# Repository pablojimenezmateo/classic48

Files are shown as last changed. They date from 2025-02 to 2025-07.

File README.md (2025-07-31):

# Classic 48
A custom 48 key split keyboard

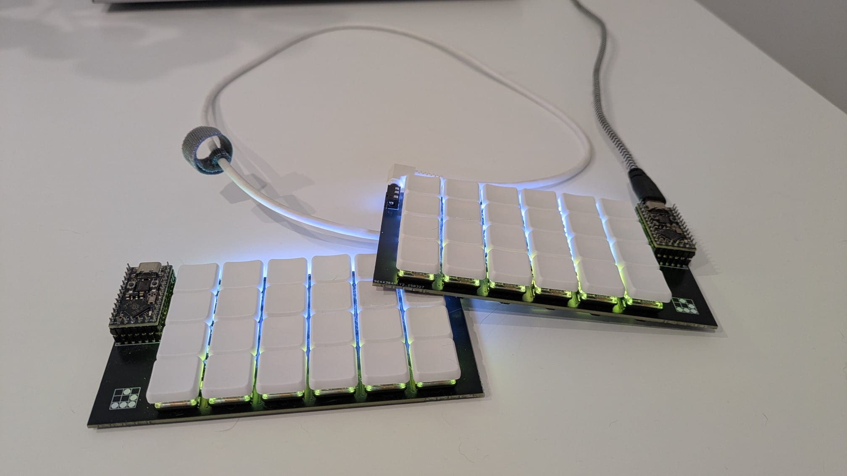
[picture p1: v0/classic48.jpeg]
classic48


# Bill Of Materials
| Name | Quantity/Variety | Item Price (€) | Shipping (€) | Link |
|--|--|--|--|--|
|Brown Choc Switches|70 pcs|47.59|0|[AliExpress](https://www.aliexpress.com/item/1005005883472162.html?spm=a2g0o.order_list.order_list_main.199.2613194dDxt0T9)|
|Choc Keycaps|10 x B type (5 pcs each)|20|4.86|[AliExpress](https://www.aliexpress.com/item/1005007966026757.html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)|
|Choc Blind Keycaps|1 x E type (5 pcs each)|2.99|4.86|[AliExpress](https://www.aliexpress.com/item/1005007966026757.html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)|
|Soldering iron|1|19.69|0|[AliExpress](https://www.aliexpress.com/item/4000019437594.html?spm=a2g0o.order_detail.order_detail_item.3.5b734d1aqwuhYo)|
|SK6812 Mini-E LEDs|1 (100 pcs)|3.49|0.09|[AliExpress](https://www.aliexpress.com/item/1005002865070175.html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)|
|RP2040 Pro Micro|2|6.38|0|[AliExpress](https://www.aliexpress.com/item/1005006787060405.html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)|
|TRRS|1 (10 pcs)|2.11|0|[AliExpress](https://www.aliexpress.com/item/33029465106.html?spm=a2g0o.order_detail.order_detail_item.3.4e99f19crF5m72)|
|Soldering mount|1|8.09|0|[AliExpress](https://www.aliexpress.com/item/1005007045716674.html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)|
|Flux pen|1|1.01|0|[AliExpress](https://www.aliexpress.com/item/1005007346959832.html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)|
|Choc Hot Swap Sockets|1 x Type B (70 pcs)|5.89|0|[AliExpress](https://www.aliexpress.com/item/1005007232040760.html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)|
|SMD diode|1 1N4148W SOD123 (100 pcs)|1.08|0|[AliExpress](https://www.aliexpress.com/item/1005005707644429.html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)|
|Multimeter|1|3.65|0|[AliExpress](https://www.aliexpress.com/item/1005007059884308.html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)|
|Desoldering braid|1 x 1.5mm 1.5m|1.59|0|[AliExpress](https://www.aliexpress.com/item/1005005398523384.html?spm=a2g0o.order_list.order_list_main.138.26131802A570A7)|
|Round female pin header|1 (10 pcs)|3.59|0.81|[AliExpress](https://www.aliexpress.com/item/33036413973.html?spm=a2g0o.order_detail.order_detail_item.3.7ef1f19cFHvYfp)|
|Round male pin header|1 (5 pcs)|2.00|1.31|[AliExpress](https://www.aliexpress.com/item/1005008053808682.html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)|
|PCB|1 (5 pcs)|10.26| 15.87 (shipping) + 29.14 (customs + handling fees DHL)|[JLCPCB](https://jlcpcb.com/)|

Grand total: **196.35 €**

# Installing the kicad libaries
1. Go to KiCad, `Preferences` -> `Configure Paths`, add new row with name `PJIMENEZ` and path to `pjimenez.kicad`
2. Go to KiCad, `Preferences` -> `Manage Footprint Libraries`, add new row with name `pjimenez` and path to `pjimenez.kicad/pjimenez.pretty`
3. Go to KiCad, `Preferences` -> `Manage Symbol Libraries`, add new row with name `pjimenez` and path to `pjimenez.kicad/pjimenez.kicad_sym`

# Firmware
Checkout the [classic48-keymap repository](https://github.com/pablojimenezmateo/classic48-keymap)

# License
This project is licensed under Creative commons Attribution 3.0 Unported, more info : http://creativecommons.org/licenses/by/3.0/deed.en_US

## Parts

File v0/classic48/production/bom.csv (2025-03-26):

Designator | Footprint | Quantity | Value | LCSC Part #
D1, D10, D11, D12, D13, D14, D15, D16, D17, D18, D19, D2, D20, D21, D22, D23, D24, D25, D26, D27, D28, D29, D3, D30, D31, D32, D33, D34, D35, D36, D37, D38, D39, D4, D40, D41, D42, D43, D44, D45, D46, D47, D48, D49, D5, D50, D6, D7, D8, D9 | Diode_1N4148-SOD123 | 50 | Diode_1N4148-SOD123
LED1, LED10, LED11, LED12, LED13, LED14, LED15, LED16, LED17, LED18, LED19, LED2, LED20, LED21, LED22, LED23, LED24, LED25, LED26, LED27, LED28, LED29, LED3, LED30, LED31, LED32, LED33, LED34, LED35, LED36, LED37, LED38, LED39, LED4, LED40, LED41, LED42, LED43, LED44, LED45, LED46, LED47, LED48, LED5, LED6, LED7, LED8, LED9 | LED_SK6812-MINI-E | 48 | LED_SK6812MINI-E
SW1, SW10, SW11, SW12, SW13, SW14, SW15, SW16, SW17, SW18, SW19, SW2, SW20, SW21, SW22, SW23, SW24, SW25, SW26, SW27, SW28, SW29, SW3, SW30, SW31, SW32, SW33, SW34, SW35, SW36, SW37, SW38, SW39, SW4, SW40, SW41, SW42, SW43, SW44, SW45, SW46, SW47, SW48, SW5, SW6, SW7, SW8, SW9 | Switch_ChocV1-hotswap | 48 | Switch
U1, U3 | RP2040_Pro_Micro | 2 | RP2040_Pro_Micro
U2, U4 | TRRS_PJ-320A | 2 | TRRS

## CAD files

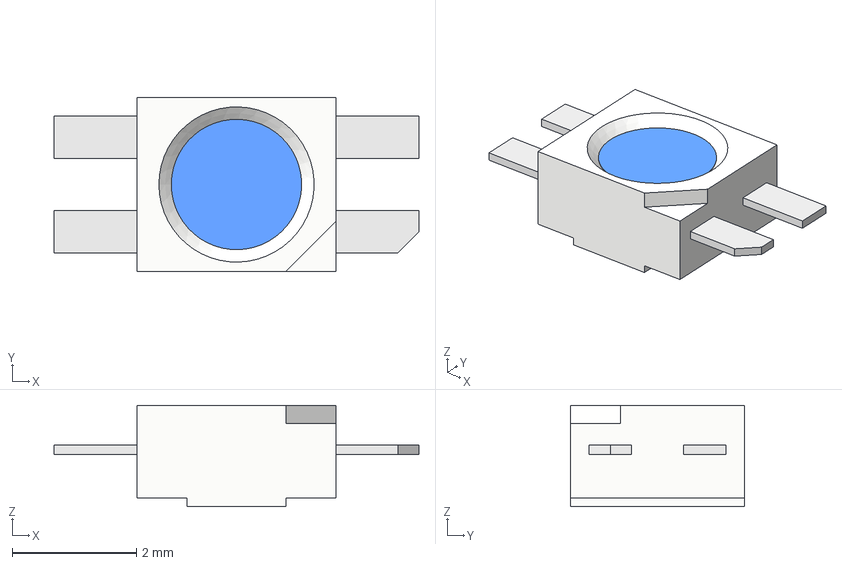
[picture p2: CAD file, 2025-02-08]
pjimenez.kicad/pjimenez.models/YS-SK6812MINI-E.step
5.88 x 2.80 x 1.63 mm

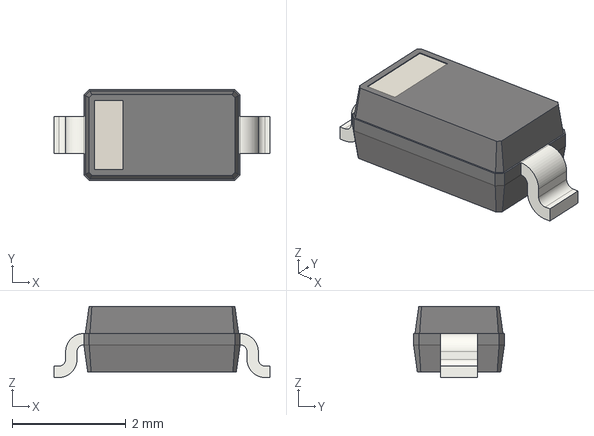
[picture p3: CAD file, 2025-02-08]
pjimenez.kicad/pjimenez.models/D_SOD-123.step
3.80 x 1.60 x 1.25 mm

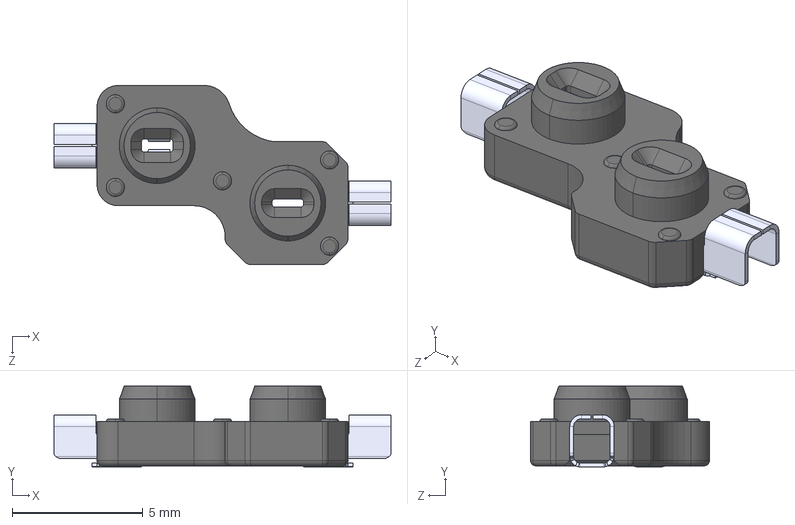
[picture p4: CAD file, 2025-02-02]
pjimenez.kicad/pjimenez.models/PG1350-socket.step
12.9 x 3.09 x 6.85 mm
pin x 2
socket

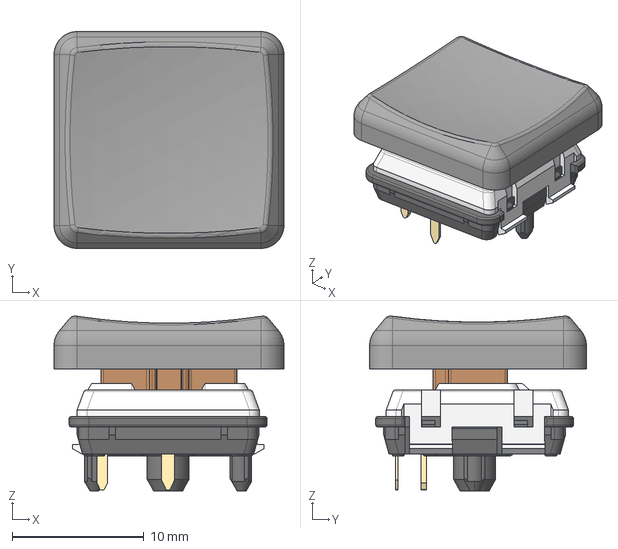
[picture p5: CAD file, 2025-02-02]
pjimenez.kicad/pjimenez.models/pg1350-mbk.step
17.4 x 16.4 x 13.3 mm
(Unsaved)
Document x 5

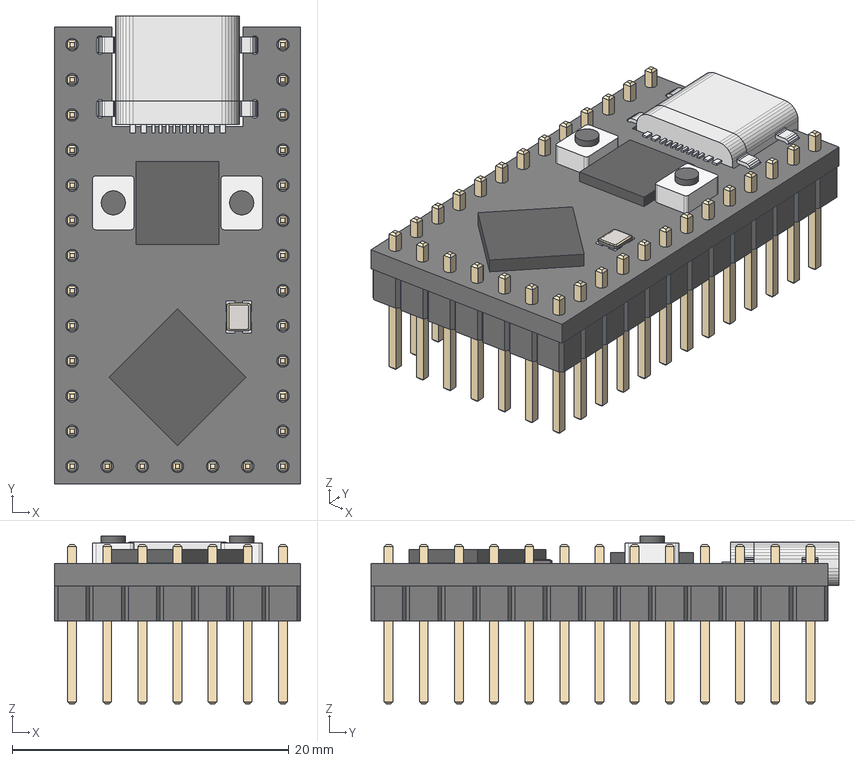
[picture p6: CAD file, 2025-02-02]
pjimenez.kicad/pjimenez.models/RP2040_Pro_Micro.step
17.8 x 33.8 x 12.1 mm
Folder 09
PinHeader_1x12_P2.54mm_Vertical.step
User Library-TYPE-C-31-M-14.step
MICRO_603 resistor 102
micro_crystal 5x3
MICRO_led
micro_MIC5219

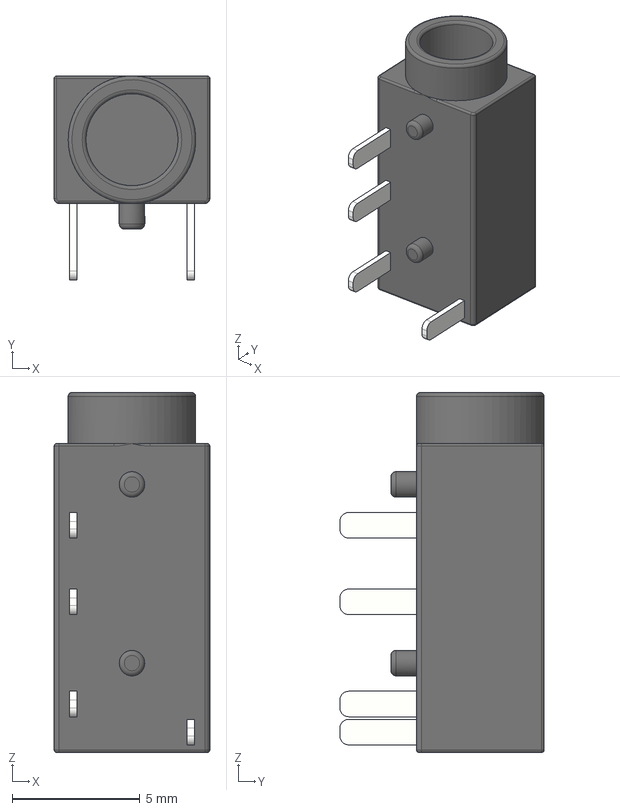
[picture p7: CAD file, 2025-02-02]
pjimenez.kicad/pjimenez.models/TRRS_PJ-320A.step
6.10 x 8.00 x 14.1 mm

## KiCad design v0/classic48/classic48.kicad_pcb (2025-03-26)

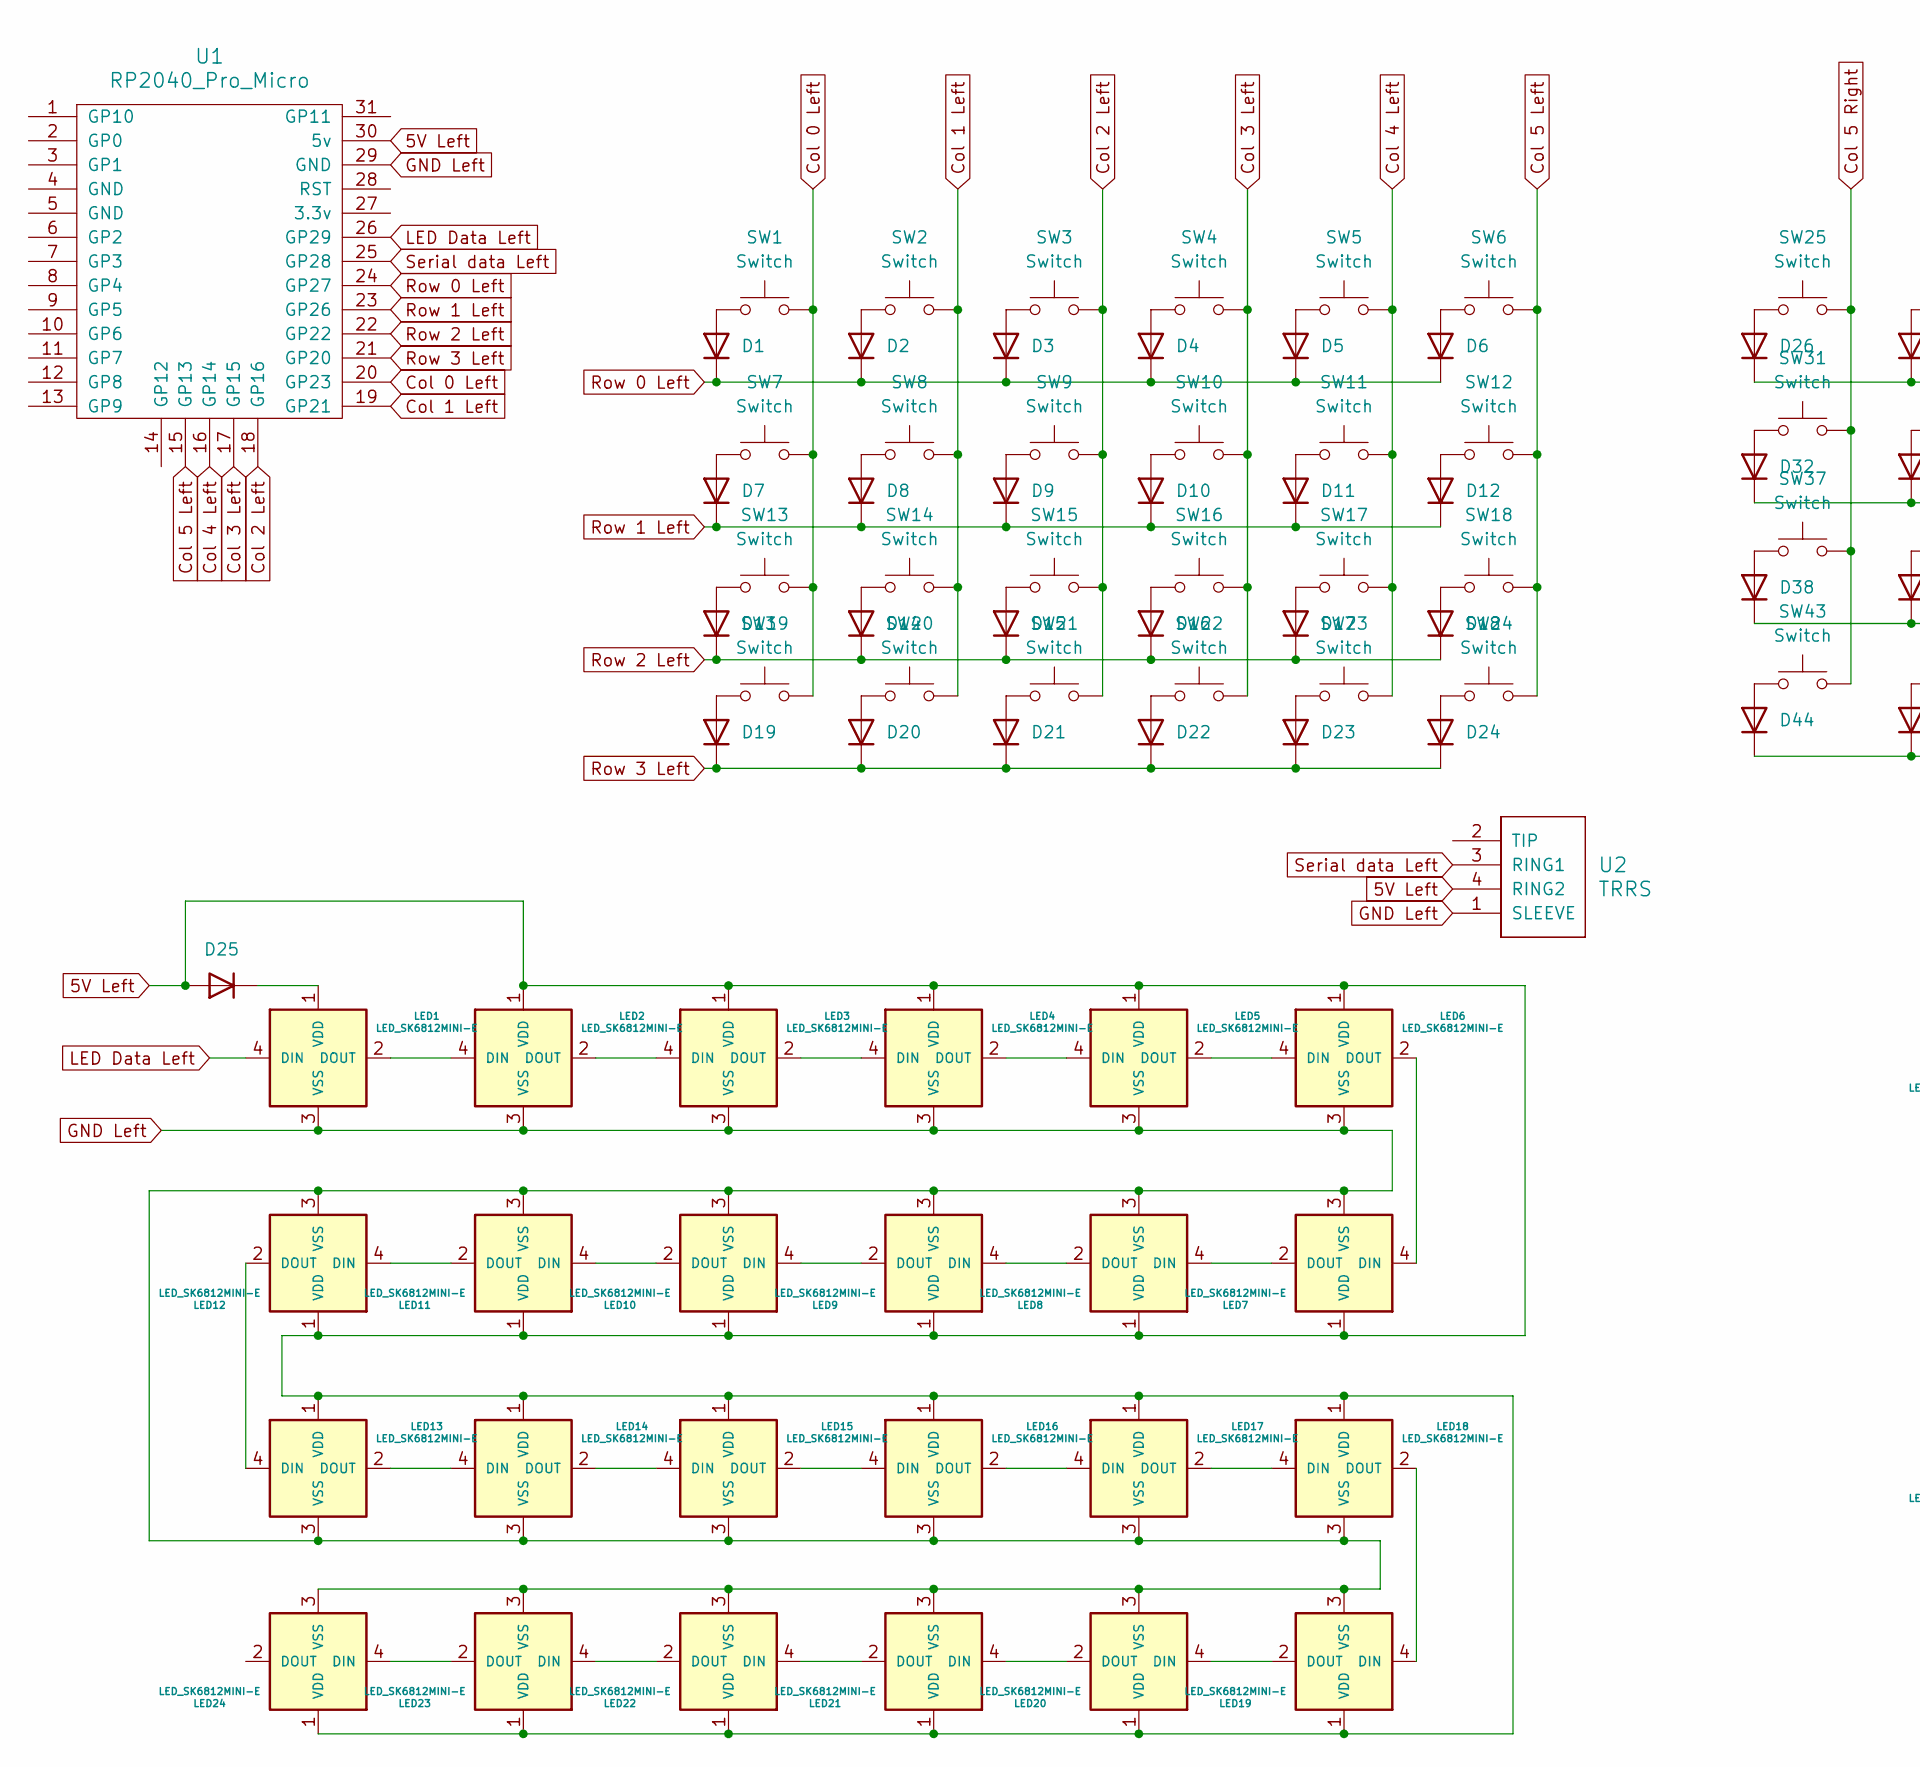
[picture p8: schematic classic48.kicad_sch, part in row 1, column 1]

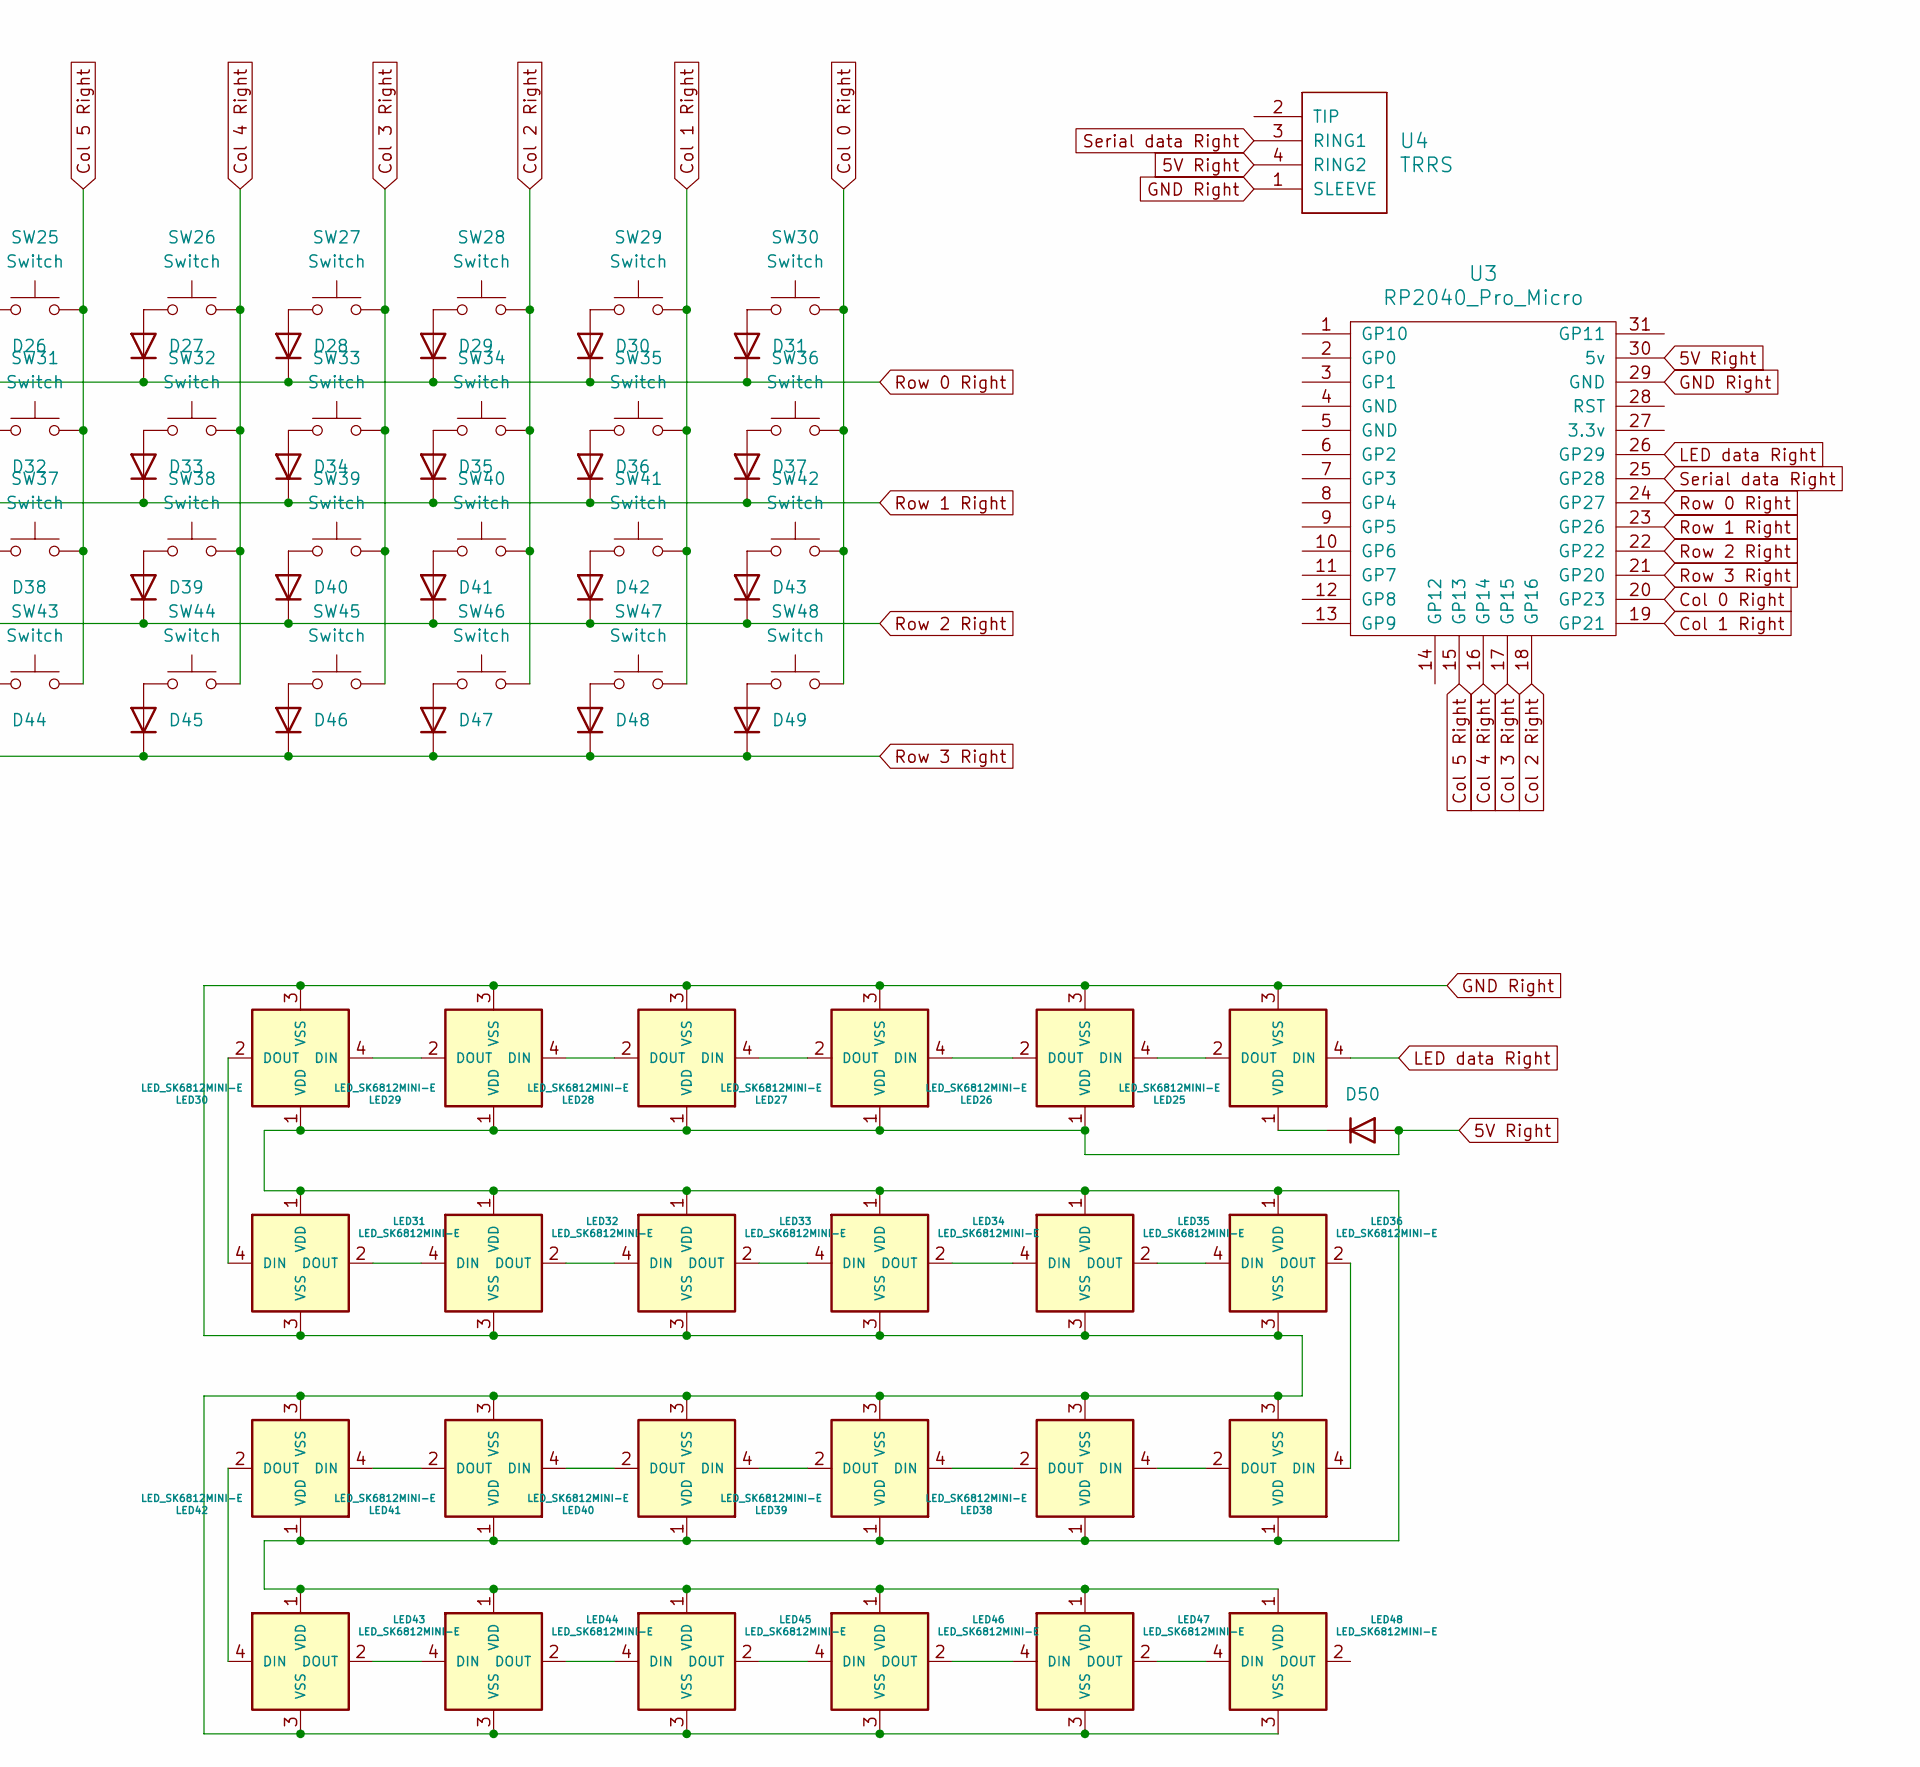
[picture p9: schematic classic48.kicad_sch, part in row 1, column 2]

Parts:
D1, D2, D3, D4, D5, D6, D7, D8, D9, D10, D11, D12, D13, D14, D15, D16, D17, D18, D19, D20, D21, D22, D23, D24, D25, D26, D27, D28, D29, D30, D31, D32, D33, D34, D35, D36, D37, D38, D39, D40, D41, D42, D43, D44, D45, D46, D47, D48, D49, D50: Diode_1N4148-SOD123
LED1, LED2, LED3, LED4, LED5, LED6, LED7, LED8, LED9, LED10, LED11, LED12, LED13, LED14, LED15, LED16, LED17, LED18, LED19, LED20, LED21, LED22, LED23, LED24, LED25, LED26, LED27, LED28, LED29, LED30, LED31, LED32, LED33, LED34, LED35, LED36, LED37, LED38, LED39, LED40, LED41, LED42, LED43, LED44, LED45, LED46, LED47, LED48: LED_SK6812MINI-E; LED_SK6812-MINI-E
SW1, SW2, SW3, SW4, SW5, SW6, SW7, SW8, SW9, SW10, SW11, SW12, SW13, SW14, SW15, SW16, SW17, SW18, SW19, SW20, SW21, SW22, SW23, SW24, SW25, SW26, SW27, SW28, SW29, SW30, SW31, SW32, SW33, SW34, SW35, SW36, SW37, SW38, SW39, SW40, SW41, SW42, SW43, SW44, SW45, SW46, SW47, SW48: Switch; Switch_ChocV1-hotswap
U1, U3: RP2040_Pro_Micro
U2, U4: TRRS; TRRS_PJ-320A

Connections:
5V Left: D25.2 (A), LED2.1 (VDD), LED3.1 (VDD), LED4.1 (VDD), LED5.1 (VDD), LED6.1 (VDD), LED7.1 (VDD), LED8.1 (VDD), LED9.1 (VDD), LED10.1 (VDD), LED11.1 (VDD), LED12.1 (VDD), LED13.1 (VDD), LED14.1 (VDD), LED15.1 (VDD), LED16.1 (VDD), LED17.1 (VDD), LED18.1 (VDD), LED19.1 (VDD), LED20.1 (VDD), LED21.1 (VDD), LED22.1 (VDD), LED23.1 (VDD), LED24.1 (VDD), U1.30 (5v), U2.4 (RING2)
5V Right: D50.2 (A), LED26.1 (VDD), LED27.1 (VDD), LED28.1 (VDD), LED29.1 (VDD), LED30.1 (VDD), LED31.1 (VDD), LED32.1 (VDD), LED33.1 (VDD), LED34.1 (VDD), LED35.1 (VDD), LED36.1 (VDD), LED37.1 (VDD), LED38.1 (VDD), LED39.1 (VDD), LED40.1 (VDD), LED41.1 (VDD), LED42.1 (VDD), LED43.1 (VDD), LED44.1 (VDD), LED45.1 (VDD), LED46.1 (VDD), LED47.1 (VDD), LED48.1 (VDD), U3.30 (5v), U4.4 (RING2)
Col 0 Left: SW1.2, SW7.2, SW13.2, SW19.2, U1.20 (GP23)
Col 0 Right: SW30.2, SW36.2, SW42.2, SW48.2, U3.20 (GP23)
Col 1 Left: SW2.2, SW8.2, SW14.2, SW20.2, U1.19 (GP21)
Col 1 Right: SW29.2, SW35.2, SW41.2, SW47.2, U3.19 (GP21)
Col 2 Left: SW3.2, SW9.2, SW15.2, SW21.2, U1.18 (GP16)
Col 2 Right: SW28.2, SW34.2, SW40.2, SW46.2, U3.18 (GP16)
Col 3 Left: SW4.2, SW10.2, SW16.2, SW22.2, U1.17 (GP15)
Col 3 Right: SW27.2, SW33.2, SW39.2, SW45.2, U3.17 (GP15)
Col 4 Left: SW5.2, SW11.2, SW17.2, SW23.2, U1.16 (GP14)
Col 4 Right: SW26.2, SW32.2, SW38.2, SW44.2, U3.16 (GP14)
Col 5 Left: SW6.2, SW12.2, SW18.2, SW24.2, U1.15 (GP13)
Col 5 Right: SW25.2, SW31.2, SW37.2, SW43.2, U3.15 (GP13)
GND Left: LED1.3 (VSS), LED2.3 (VSS), LED3.3 (VSS), LED4.3 (VSS), LED5.3 (VSS), LED6.3 (VSS), LED7.3 (VSS), LED8.3 (VSS), LED9.3 (VSS), LED10.3 (VSS), LED11.3 (VSS), LED12.3 (VSS), LED13.3 (VSS), LED14.3 (VSS), LED15.3 (VSS), LED16.3 (VSS), LED17.3 (VSS), LED18.3 (VSS), LED19.3 (VSS), LED20.3 (VSS), LED21.3 (VSS), LED22.3 (VSS), LED23.3 (VSS), LED24.3 (VSS), U1.29 (GND), U2.1 (SLEEVE)
GND Right: LED25.3 (VSS), LED26.3 (VSS), LED27.3 (VSS), LED28.3 (VSS), LED29.3 (VSS), LED30.3 (VSS), LED31.3 (VSS), LED32.3 (VSS), LED33.3 (VSS), LED34.3 (VSS), LED35.3 (VSS), LED36.3 (VSS), LED37.3 (VSS), LED38.3 (VSS), LED39.3 (VSS), LED40.3 (VSS), LED41.3 (VSS), LED42.3 (VSS), LED43.3 (VSS), LED44.3 (VSS), LED45.3 (VSS), LED46.3 (VSS), LED47.3 (VSS), LED48.3 (VSS), U3.29 (GND), U4.1 (SLEEVE)
LED Data Left: LED1.4 (DIN), U1.26 (GP29)
LED data Right: LED25.4 (DIN), U3.26 (GP29)
unnamed: D1.2 (A), SW1.1
unnamed: D2.2 (A), SW2.1
unnamed: D3.2 (A), SW3.1
unnamed: D4.2 (A), SW4.1
unnamed: D5.2 (A), SW5.1
unnamed: D6.2 (A), SW6.1
unnamed: D7.2 (A), SW7.1
unnamed: D8.2 (A), SW8.1
unnamed: D9.2 (A), SW9.1
unnamed: D10.2 (A), SW10.1
unnamed: D11.2 (A), SW11.1
unnamed: D12.2 (A), SW12.1
unnamed: D13.2 (A), SW13.1
unnamed: D14.2 (A), SW14.1
unnamed: D15.2 (A), SW15.1
unnamed: D16.2 (A), SW16.1
unnamed: D17.2 (A), SW17.1
unnamed: D18.2 (A), SW18.1
unnamed: D19.2 (A), SW19.1
unnamed: D20.2 (A), SW20.1
unnamed: D21.2 (A), SW21.1
unnamed: D22.2 (A), SW22.1
unnamed: D23.2 (A), SW23.1
unnamed: D24.2 (A), SW24.1
unnamed: D25.1 (K), LED1.1 (VDD)
unnamed: D26.2 (A), SW25.1
unnamed: D27.2 (A), SW26.1
unnamed: D28.2 (A), SW27.1
unnamed: D29.2 (A), SW28.1
unnamed: D30.2 (A), SW29.1
unnamed: D31.2 (A), SW30.1
unnamed: D32.2 (A), SW31.1
unnamed: D33.2 (A), SW32.1
unnamed: D34.2 (A), SW33.1
unnamed: D35.2 (A), SW34.1
unnamed: D36.2 (A), SW35.1
unnamed: D37.2 (A), SW36.1
unnamed: D38.2 (A), SW37.1
unnamed: D39.2 (A), SW38.1
unnamed: D40.2 (A), SW39.1
unnamed: D41.2 (A), SW40.1
unnamed: D42.2 (A), SW41.1
unnamed: D43.2 (A), SW42.1
unnamed: D44.2 (A), SW43.1
unnamed: D45.2 (A), SW44.1
unnamed: D46.2 (A), SW45.1
unnamed: D47.2 (A), SW46.1
unnamed: D48.2 (A), SW47.1
unnamed: D49.2 (A), SW48.1
unnamed: D50.1 (K), LED25.1 (VDD)
unnamed: LED1.2 (DOUT), LED2.4 (DIN)
unnamed: LED2.2 (DOUT), LED3.4 (DIN)
unnamed: LED3.2 (DOUT), LED4.4 (DIN)
unnamed: LED4.2 (DOUT), LED5.4 (DIN)
unnamed: LED5.2 (DOUT), LED6.4 (DIN)
unnamed: LED6.2 (DOUT), LED7.4 (DIN)
unnamed: LED7.2 (DOUT), LED8.4 (DIN)
unnamed: LED8.2 (DOUT), LED9.4 (DIN)
unnamed: LED9.2 (DOUT), LED10.4 (DIN)
unnamed: LED10.2 (DOUT), LED11.4 (DIN)
unnamed: LED11.2 (DOUT), LED12.4 (DIN)
unnamed: LED12.2 (DOUT), LED13.4 (DIN)
unnamed: LED13.2 (DOUT), LED14.4 (DIN)
unnamed: LED14.2 (DOUT), LED15.4 (DIN)
unnamed: LED15.2 (DOUT), LED16.4 (DIN)
unnamed: LED16.2 (DOUT), LED17.4 (DIN)
unnamed: LED17.2 (DOUT), LED18.4 (DIN)
unnamed: LED18.2 (DOUT), LED19.4 (DIN)
unnamed: LED19.2 (DOUT), LED20.4 (DIN)
unnamed: LED20.2 (DOUT), LED21.4 (DIN)
unnamed: LED21.2 (DOUT), LED22.4 (DIN)
unnamed: LED22.2 (DOUT), LED23.4 (DIN)
unnamed: LED23.2 (DOUT), LED24.4 (DIN)
unnamed: LED25.2 (DOUT), LED26.4 (DIN)
unnamed: LED26.2 (DOUT), LED27.4 (DIN)
unnamed: LED27.2 (DOUT), LED28.4 (DIN)
unnamed: LED28.2 (DOUT), LED29.4 (DIN)
unnamed: LED29.2 (DOUT), LED30.4 (DIN)
unnamed: LED30.2 (DOUT), LED31.4 (DIN)
unnamed: LED31.2 (DOUT), LED32.4 (DIN)
unnamed: LED32.2 (DOUT), LED33.4 (DIN)
unnamed: LED33.2 (DOUT), LED34.4 (DIN)
unnamed: LED34.2 (DOUT), LED35.4 (DIN)
unnamed: LED35.2 (DOUT), LED36.4 (DIN)
unnamed: LED36.2 (DOUT), LED37.4 (DIN)
unnamed: LED37.2 (DOUT), LED38.4 (DIN)
unnamed: LED38.2 (DOUT), LED39.4 (DIN)
unnamed: LED39.2 (DOUT), LED40.4 (DIN)
unnamed: LED40.2 (DOUT), LED41.4 (DIN)
unnamed: LED41.2 (DOUT), LED42.4 (DIN)
unnamed: LED42.2 (DOUT), LED43.4 (DIN)
unnamed: LED43.2 (DOUT), LED44.4 (DIN)
unnamed: LED44.2 (DOUT), LED45.4 (DIN)
unnamed: LED45.2 (DOUT), LED46.4 (DIN)
unnamed: LED46.2 (DOUT), LED47.4 (DIN)
unnamed: LED47.2 (DOUT), LED48.4 (DIN)
Row 0 Left: D1.1 (K), D2.1 (K), D3.1 (K), D4.1 (K), D5.1 (K), D6.1 (K), U1.24 (GP27)
Row 0 Right: D26.1 (K), D27.1 (K), D28.1 (K), D29.1 (K), D30.1 (K), D31.1 (K), U3.24 (GP27)
Row 1 Left: D7.1 (K), D8.1 (K), D9.1 (K), D10.1 (K), D11.1 (K), D12.1 (K), U1.23 (GP26)
Row 1 Right: D32.1 (K), D33.1 (K), D34.1 (K), D35.1 (K), D36.1 (K), D37.1 (K), U3.23 (GP26)
Row 2 Left: D13.1 (K), D14.1 (K), D15.1 (K), D16.1 (K), D17.1 (K), D18.1 (K), U1.22 (GP22)
Row 2 Right: D38.1 (K), D39.1 (K), D40.1 (K), D41.1 (K), D42.1 (K), D43.1 (K), U3.22 (GP22)
Row 3 Left: D19.1 (K), D20.1 (K), D21.1 (K), D22.1 (K), D23.1 (K), D24.1 (K), U1.21 (GP20)
Row 3 Right: D44.1 (K), D45.1 (K), D46.1 (K), D47.1 (K), D48.1 (K), D49.1 (K), U3.21 (GP20)
Serial data Left: U1.25 (GP28), U2.3 (RING1)
Serial data Right: U3.25 (GP28), U4.3 (RING1)

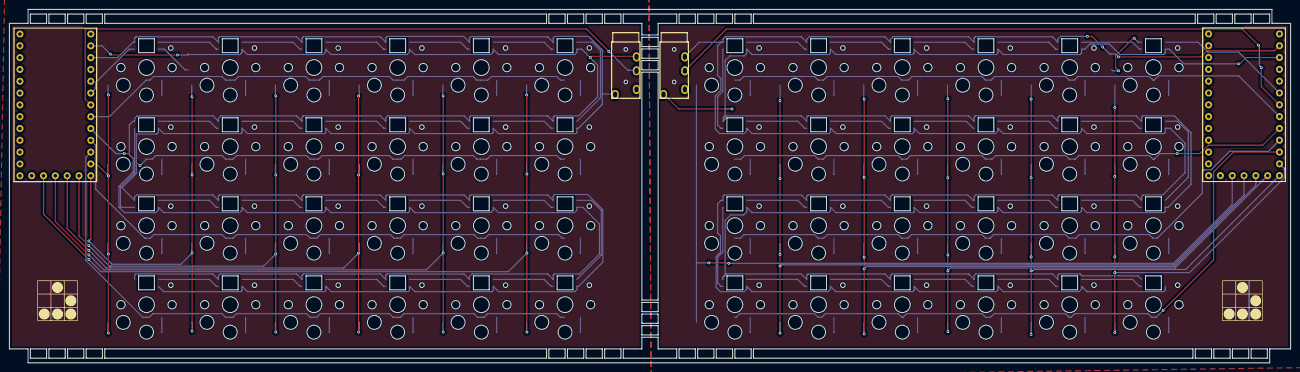
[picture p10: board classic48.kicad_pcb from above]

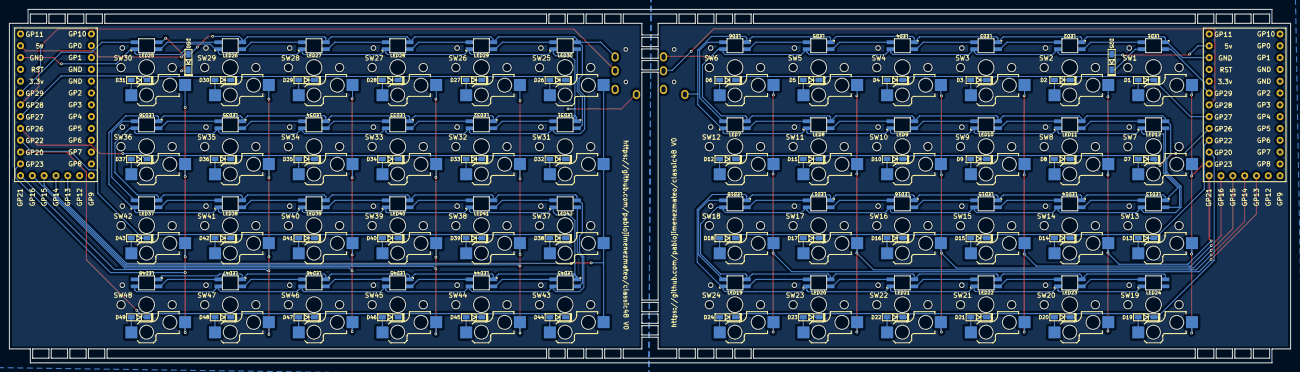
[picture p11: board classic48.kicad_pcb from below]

Board: 2 copper layers, 275.5 x 76.0 mm, 150 parts (50 on the bottom side), 124 nets.

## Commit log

2025-02-02 feat: libraries tested
    [classic48.kicad_pcb, classic48.kicad_sch]
2025-02-08 feat: schematic for left side
    [classic48.kicad_pcb, classic48.kicad_sch]
2025-02-08 feat: position all right side diodes
    [classic48.kicad_pcb]
2025-02-08 fix: bring diodes to background
    [classic48.kicad_pcb]
2025-02-08 feat: all LEDs in place
    [classic48.kicad_pcb]
2025-02-08 chore: remove soldered 3D models
    [D_SOD-123 Soldered.step, D_SOD-123.step, YS-SK6812MINI-E Soldered.step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]
2025-02-08 feat: add GND marker to 6812
    [classic48.kicad_pcb]
2025-02-08 feat: LED Vcc
    [classic48.kicad_pcb]
2025-02-08 feat: LEDs and TRRS fully connected
    [classic48.kicad_pcb, classic48.kicad_sch]
2025-02-08 feat: finish tracks
    [classic48.kicad_pcb, classic48.kicad_sch]
2025-02-09 fix: DRC errors except LEDS
    [classic48.kicad_pcb]
2025-02-09 feat: improve silk screen pin placement for 2040
    [classic48.kicad_pcb]
2025-02-12 fix: left side LEDs were connected incorrectly feat: right side schema
    [classic48.kicad_pcb, classic48.kicad_sch]
2025-02-24 fix: LED connections
    [classic48.kicad_pcb]
2025-02-27 feat: right switches positions
    [classic48.kicad_pcb]
2025-02-27 feat: LED and switch positions
    [classic48.kicad_pcb]
2025-02-27 feat: position MCU and TRRS
    [classic48.kicad_pcb]
2025-03-02 feat: fully wired
    [classic48.kicad_pcb]
2025-03-14 wip: working on the cuts
    [classic48.kicad_pcb]
2025-03-26 feat: add structure
    [classic48.kicad_pcb]
2025-03-26 feat: add graphics
    [classic48.kicad_pcb]
2025-03-26 feat: fill zone and export
    [bom.csv, classic48.kicad_pcb, designators.csv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]
2025-03-26 feat: sent to print
2025-07-11 feat: add image
    [bom.csv, classic48.kicad_pcb, classic48.kicad_sch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]
2025-07-12 feat: add BOM
